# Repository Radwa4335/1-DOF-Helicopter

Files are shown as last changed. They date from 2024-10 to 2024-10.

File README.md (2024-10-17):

# 1-DOF-Helicopter with PD Controller
Project Overview
------------------
This project demonstrates the design and implementation of a 1-degree-of-freedom (1-DOF) helicopter model controlled using a Proportional-Derivative (PD) controller. The system focuses on controlling the pitch angle of the helicopter using real-time feedback from sensors and a control loop.

System Components
------------------
Arduino UNO: Used for signal processing and control implementation.
Coreless Motor: Drives the helicopter’s pitch movement.
MPU 6050 IMU Sensor: Provides real-time feedback on the helicopter's pitch angle.

Implementation
-----------------
The LabVIEW LINX Toolkit was used to interface with the Arduino UNO using serial communication.

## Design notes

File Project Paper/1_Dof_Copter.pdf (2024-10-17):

## Proportional-Derivative Control of a One Degree of Freedom Helicopter System: Dynamics and Implementation

Radwa Waheed 120200228 and Mohamed Khaled Mohamed 120210346 Under the Supervision of Prof. Ayman Nadaa

aEgypt Japan University of Science and Technology, , Borg El-Arab, , Alexandria, Egypt

Abstract

This study delves into the dynamics and control strategies of a One Degree of Freedom (One-DOF) helicopter system, serving as a simplified model for understanding rotary-wing aircraft behavior. The research focuses on addressing challenges related to stability and precision in helicopter flight, with a specific emphasis on the application of a Proportional-Derivative (PD) controller. The mechanical structure incorporates essential components such as a coreless motor, MPU 6050 IMU sensor, L298 motor driver, and an Arduino UNO microprocessor. Through the LabVIEW LINX Toolkit, a serial communication interface is established with the Arduino UNO to acquire gyroscope data from the MPU6050. Experimental results highlight the empirical determination of PD controller coefficients (Kp and Td) through systematic testing, showcasing the PD controller’s effectiveness in regulating the system’s motion.

Keywords: Rotary-Wing Aircraft Dynamics, PD Controller Tuning, One-DOF Helicopter Model, Arduino UNO Interface

### 1. Introduction

The one-degree-of-freedom helicopter, commonly known as the single-rotor helicopter, serves as a pivotal and streamlined model essential for comprehending the intricate dynamics and control principles inherent in rotary-wing aircraft. Within this system, the helicopter’s motion is intentionally confined to a singular rotational degree of freedom along its axis, strategically providing an optimal platform for the in-depth study of fundamental control strategies. This deliberate simplification distills the inherent complexities associated with full-scale helicopters, allowing researchers and engineers to focus with precision on critical aspects of control theory and dynamics. Within the realm of helicopter operations, a paramount challenge resides in the maintenance of stability and precision during flight. To address this challenge, sophisticated control algorithms are employed, with the Proportional-Derivative (PD) controller emerging as a preeminent choice. The PD controller stands as a universally embraced feedback control mechanism, skillfully adjusting the system’s behavior based on both the prevailing error and its rate of change. This strategic implementation empowers engineers to masterfully stabilize and regulate the helicopter’s motion, ensuring a responsive and meticulously controlled flight.

### 2. Materials

The essential components employed in this study are meticulously cataloged in Table 1, presenting a detailed inventory accompanied by visual representations, including Arduino UNO, Sensor Module, Coreless Motor, Propeller, L298N Motor Driver, and filament for the 3D printing of the structure.

Component | Image

Arduino UNO

IMU MPU6050

Coreless Motor

Propeller

L298N Motor Driver

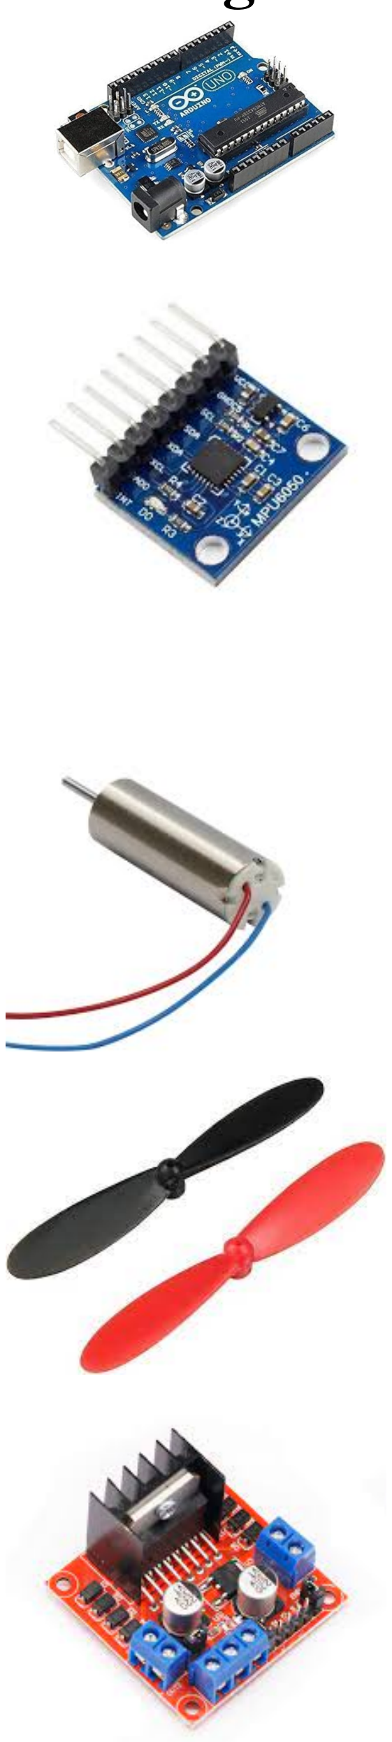
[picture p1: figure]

Table 1: Table of Components

Preprint submitted to Nuclear Physics A | January 20, 2024

### 3. Mathematical Model of the System

The equation of motion of the system is given by:

Jθ¨ = fthLm + mmgLmθ + msgLsθ

The Laplace-transformed equation is given by:

Fth(s) =

J
Lm

s

2Θ(s) + mmgsΘ(s) −

Ls
Lm

msgsΘ(s)

Fth(s) =

J
Lm

s

2 + mmgs −

Ls
Lm

msgs!
Θ(s)

G(s) =

1

J
Lm

s

2 + mmgs −

Ls
Lm

msgs

Given mm = 4.1674 grams, ms = 1.688 grams, Lm = 6.2 cm, Ls = 6.2 cm, mrod = 3.7146 grams, and Lrod = 16.1 cm, the open loop transfer function is given by:

G(s) =

1931.464
s

2 + 57.944

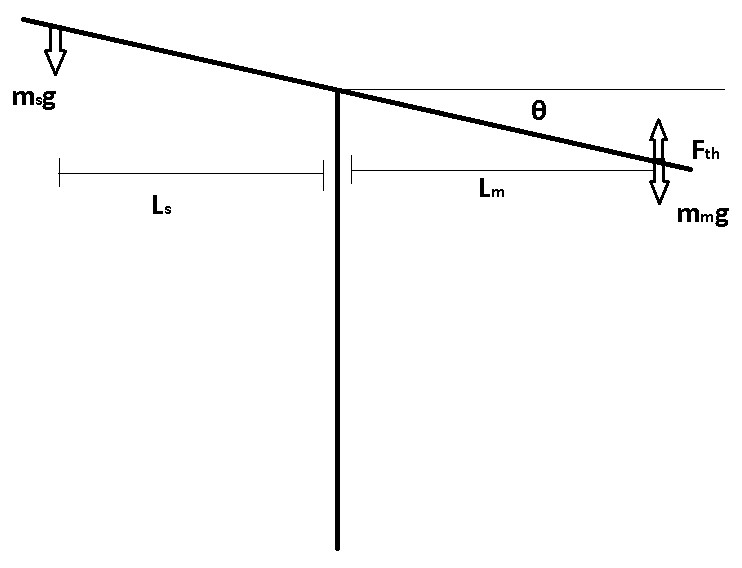
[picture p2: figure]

Figure 1: A Schematic of the System

The block diagram of the system us presendted in figure 3.

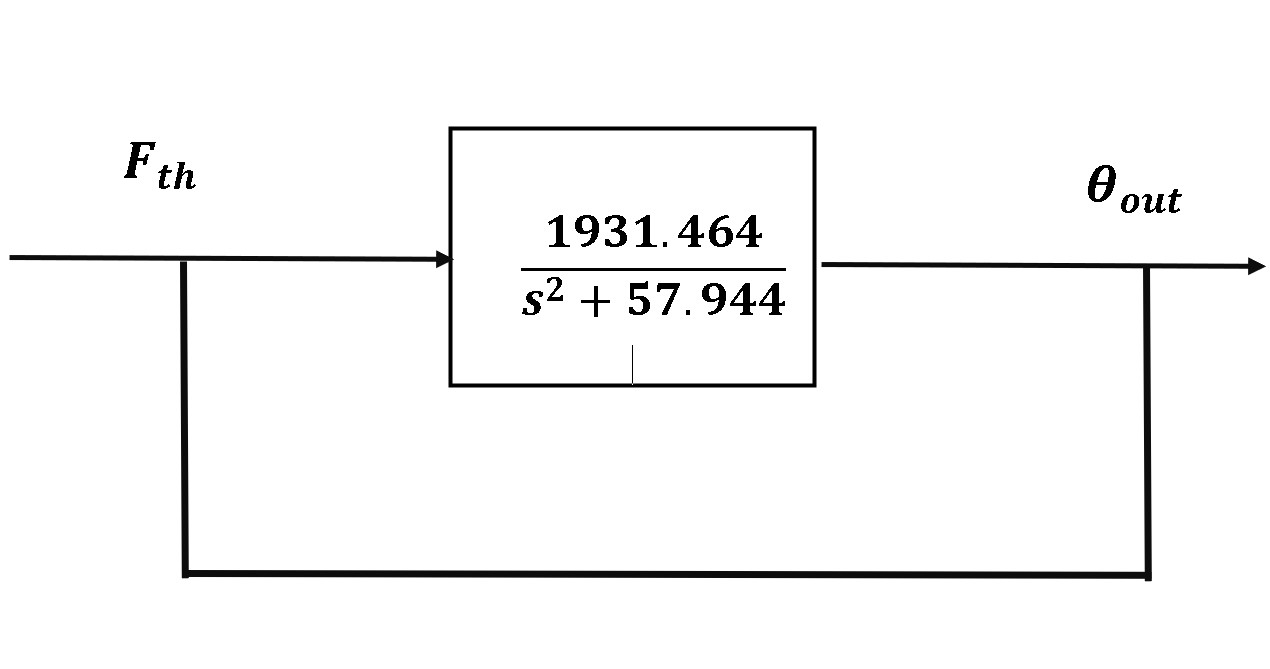
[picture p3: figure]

Figure 2: Block Diagram of the System

### 4. System Analysis and Controller Design

In the course of our investigation utilizing LabVIEW, we conducted a comprehensive analysis of the system, the results of which are presented in Figure 3 showcasing the system’s step response and Figure 4 illustrating the root locus. Notably, our findings indicate that the system exhibits instability, with dominant poles positioned along the imaginary axis. This significant observation provides valuable insights into the dynamic behavior of the system, specifically highlighting the presence of critical stability issues warranting further investigation and potential remedial measures.

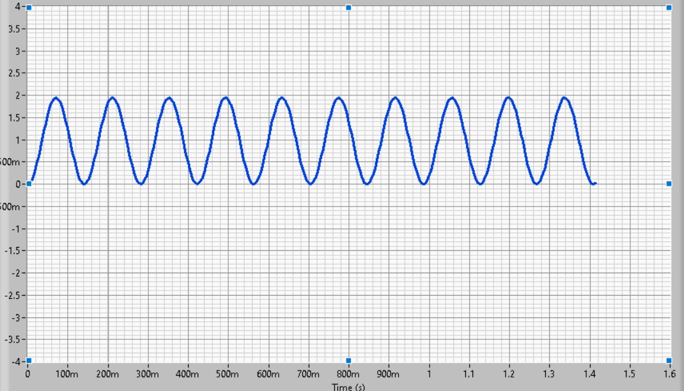
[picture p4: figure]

Figure 3: Step Response of the Uncompensated System

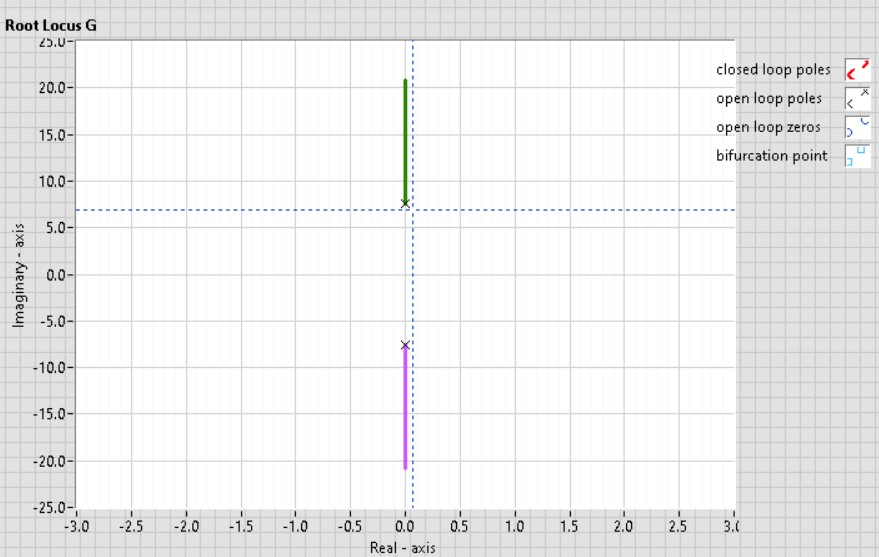
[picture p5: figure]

Figure 4: Root locus of the Uncompensated System

Commencing the design of the Proportional-Derivative (PD) controller involves the determination of critical parameters, specifically the critical gain (Kcr) and critical time (Pcr), essential for configuring the system’s stability and performance characteristics. And they were obtained as follows:
The characteristic equation is given by:

δ = s

2 + 1989.408

So, The critical gain is obtained from the gain of the system as: Kcrb = 1931.464.
By substituting s = jω into the characteristic equation, we obtain:

∆ = (jω)

2 + 1989.408

Simplifying further:

ω

2 = 1989.408

Hence, ω = 44.6

Therefore, the corresponding Critical periodic time (Pcr) is given by:

Pcr =

ω
2π

= 7.1 s

So, the values of the Proportional Gain (Kp) and Derivative Time (Td) obtained using LabVIEW are Kp = 4.5 and Td = 0.1, respectively.
The Root Locus and Step Response of the compensated system are illustrated in Figures 5 and 6, respectively. The analysis reveals a notable enhancement in system stability, achieving a settling time of less than 100 ms.

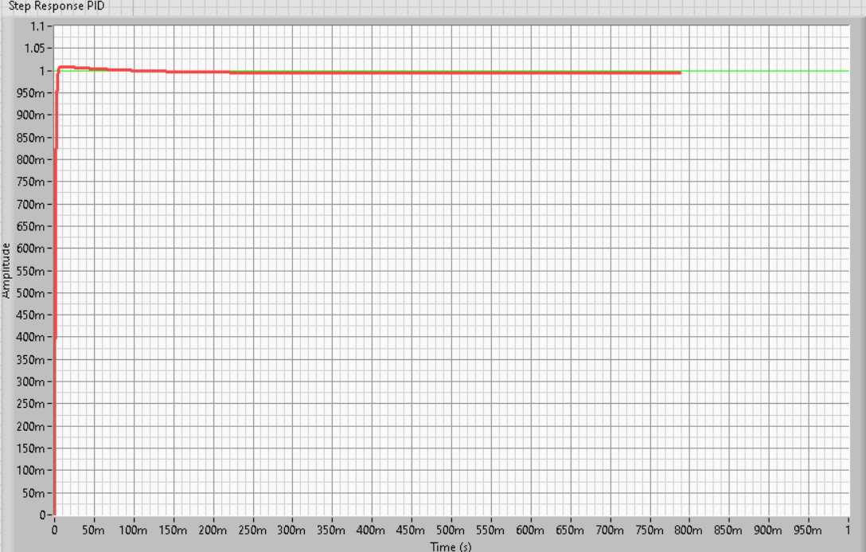
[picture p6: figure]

Figure 5: Step Response of the Compensated System

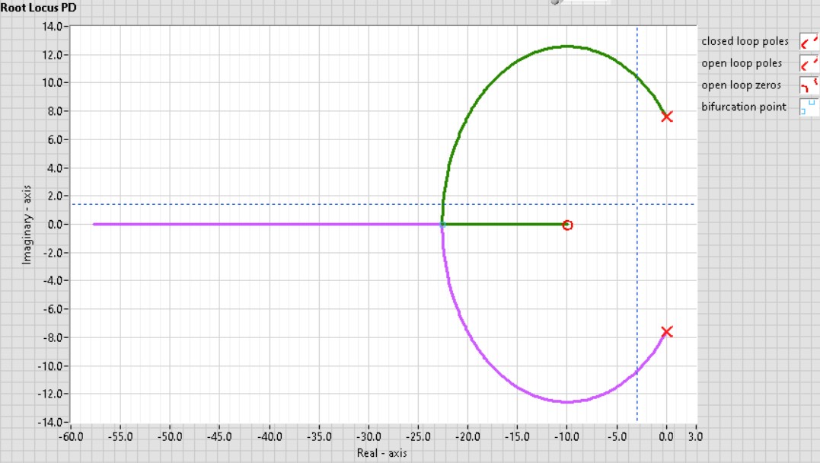
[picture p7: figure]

Figure 6: Root locus of the Compensated System

### 5. Real world Implementation

5.1. Hardware:
The project commenced with the acquisition of a 3D CAD model, meticulously tailored to meet our design specifications. After the design refinement, the model underwent fabrication through precision 3D printing technology. The mechanical configuration of the One-Degree-of-Freedom (One-DOF) helicopter system features a foundational base and two vertical plates, strategically separated by a support plate. Notably, a cylindrical structure, intricately connected to the main rod through precision bearings, constitutes a pivotal component of the system. Figure 7 encapsulates the comprehensive Solid Works drawing, providing an insightful visual representation of the intricacies inherent in the One-DOF helicopter’s mechanical structure.

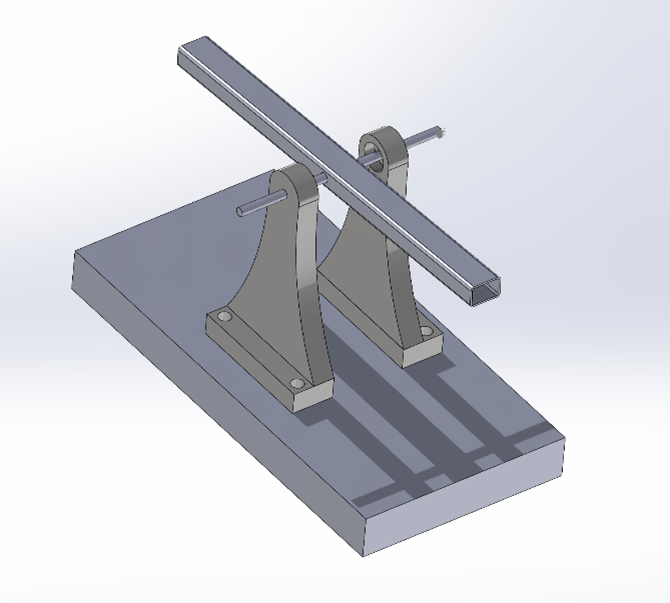
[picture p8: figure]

Figure 7: CAD Model of One-DOF Helicopter

The interconnection of the various components of the system, including the Coreless Motor, IMU sensor (MPU 6050), Motor Driver (L298), and Arduino UNO microprocessor, is illustrated in Figure 8.

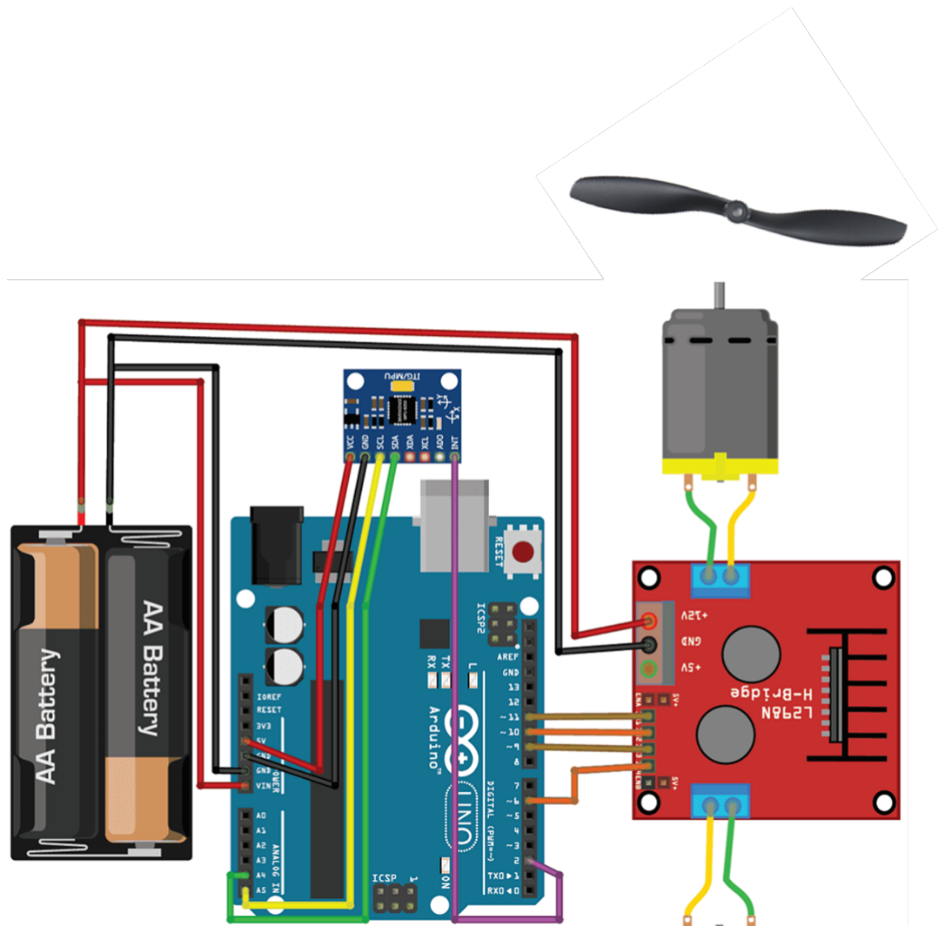
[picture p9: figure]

Figure 8: Interconnection of Components

5.2. Software:

The LabVIEW LINX Toolkit facilitated the interfacing with the Arduino UNO through serial communication. The interface was tailored to acquire gyroscope readings from the MPU6050. The implementation involves a while loop to continuously retrieve angle readings from the IMU, calculate motor power based on these readings, and apply the power to the plant. Figures (9) and (10) depict the front panel and block diagram of the LINX VI, respectively.

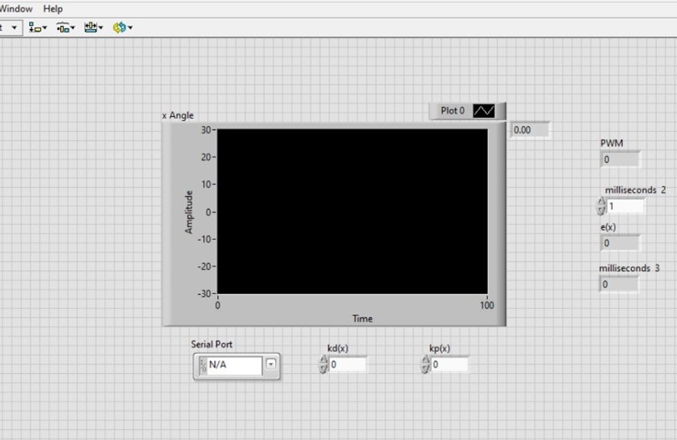
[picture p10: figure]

Figure 9: Front Panel illustrating real-time gyroscope readings

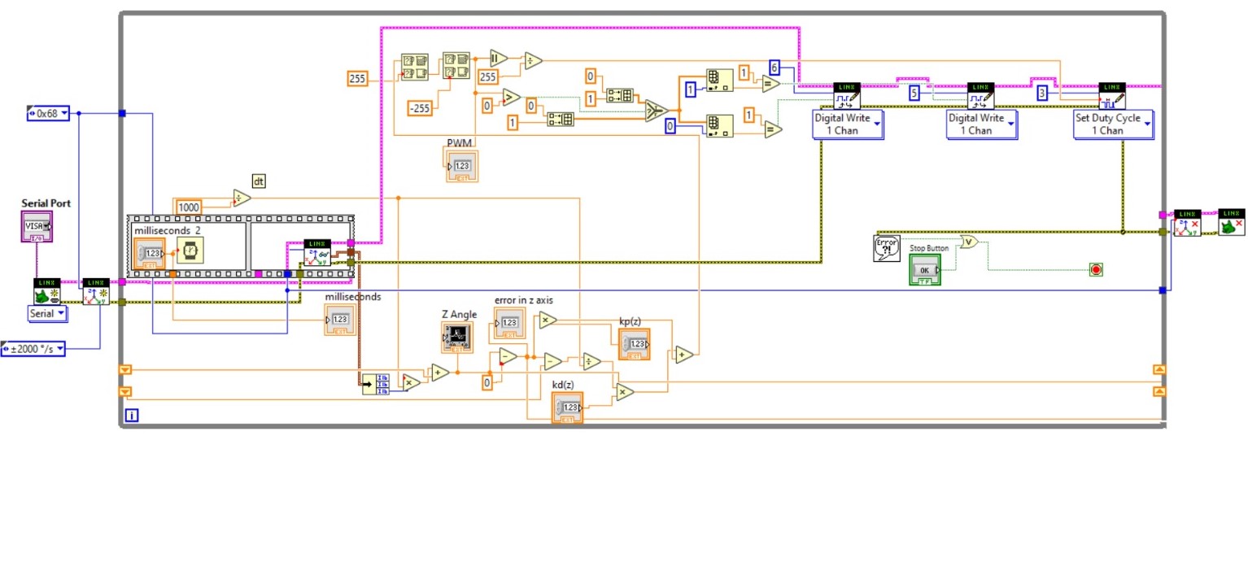
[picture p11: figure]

Figure 10: Block Diagram depicting the dynamic motor power application for plant control

5.3. Tuning of PD Controller Parameters:

The PD controller parameter coefficients, Kp and Td, were empirically determined in the experimentation process. Figure (11-a, b) showcases the system’s response under different Kp and Td values. Through analysis, it was observed that Kp = 4 and Td = 0.01 yielded the optimal response, demonstrating the effectiveness of these tuned parameters.

Future Recommendations

1. **State Feedback Theories Implementation:** Explore the application of advanced state feedback theories for control system design. Investigate techniques such as Linear Quadratic Regulator (LQR) or State Feedback with Observer for improved stability and performance.

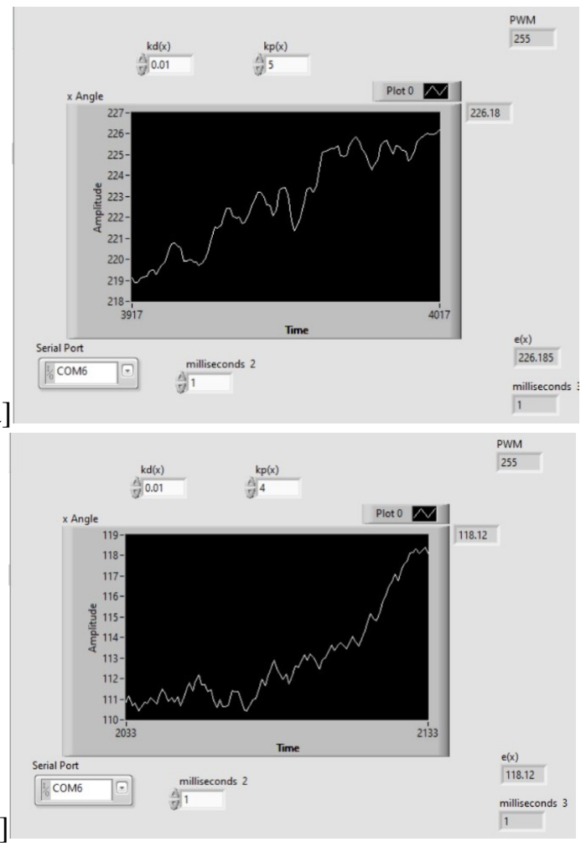
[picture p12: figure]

[Figure a]

[Figure b]

Figure 11: Various Instances from the Tuning Trials of PD Controller Parameters

2. **Sensor Reading Filtering with Kalman Filter:** Implement Kalman filtering techniques for sensor data fusion to enhance the accuracy and reliability of the system’s measurements. This can lead to improved control precision and robustness against noise and disturbances.
3. **Extension to Three Degrees of Freedom (3-DOF):** Consider expanding the project to a Three Degrees of Freedom (3-DOF) helicopter system. This extension would involve additional design considerations, such as incorporating lateral motion, and providing a more comprehensive platform for studying and implementing control strategies.

Conclusion

In conclusion, this project has laid the groundwork for the exploration and implementation of sophisticated control strategies and sensor technologies in the design of a One-Degreeof-Freedom helicopter system. The successful application of a Proportional-Derivative controller showcased the system’s stability and precision during vertical motion. Future endeavors could further advance the project by incorporating state feedback theories for enhanced control, implementing Kalman filters to refine sensor readings, and expanding the system to Three Degrees of Freedom (3-DOF) for a more comprehensive study. These recommendations open avenues for deeper research, innovation, and the potential application of the developed insights in diverse technological domains.

Acknowledgements

The completion of this research is attributed to Professor Ayman Nada’s exceptional mentorship and unwavering support. Special thanks to Teaching Assistant Hend Abdelaziz for valuable assistance, and to the university labs for essential resources. Their collective contributions were indispensable to the success of this endeavor.

References

[1] Mane, R., Mahapatro, K. A. Gundecha, A. D., (2019). “Single Degree of Freedom Helicopter Model: Laboratory Setup Design”. 2019 International Conference on Advances in Computing, Communication and Control (ICAC3), IEEE, Mumbai, India. [2] Jafar, A., Ahmad, S. M. Ahmed N.

(2016). ”Mathematical modeling and control law design for 1DOF Quadcopter flight dynamics,” 2016 International Conference on Computing, Electronic and Electrical Engineering (ICE Cube), pp. 79-84, IEEE, Quetta, Pakistan.

[3] QNET Vertical take-off and landing trainer for NI-ELVIS, Quanser Inc., 2009.

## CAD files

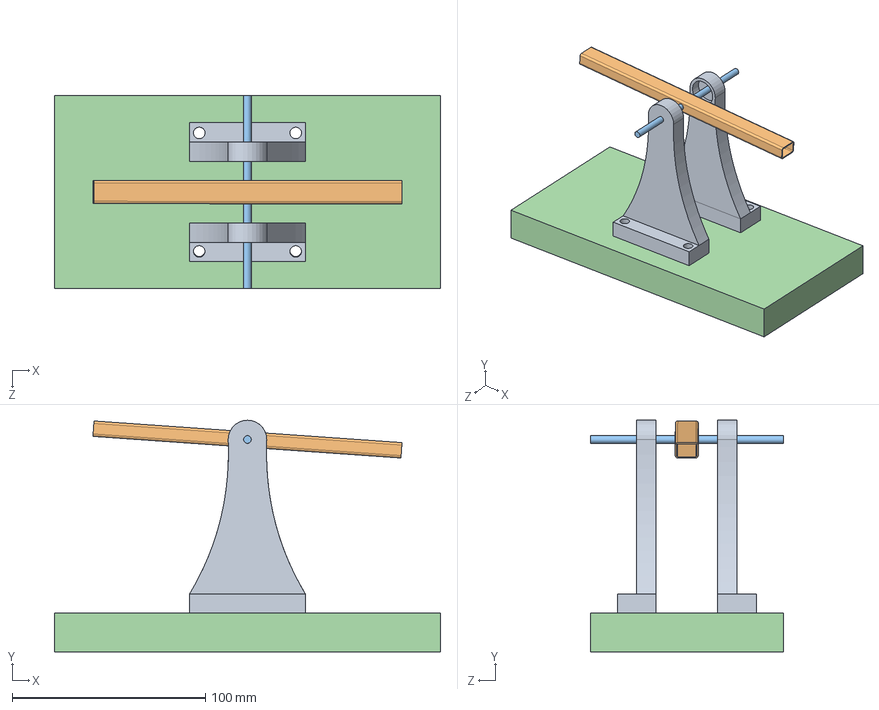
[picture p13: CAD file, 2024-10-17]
SOLIDWORKS Design/Montaj3.SLDASM
200.0 x 120.0 x 100.2 mm
Parça3 x 2
profil
saplama
base

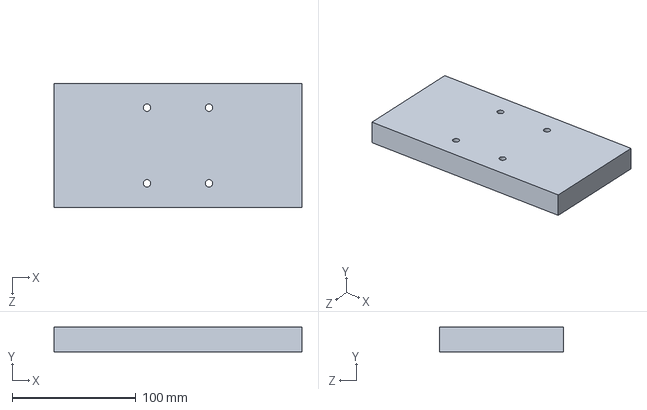
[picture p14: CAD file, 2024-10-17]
SOLIDWORKS Design/base.SLDPRT
200.0 x 20.0 x 100.0 mm

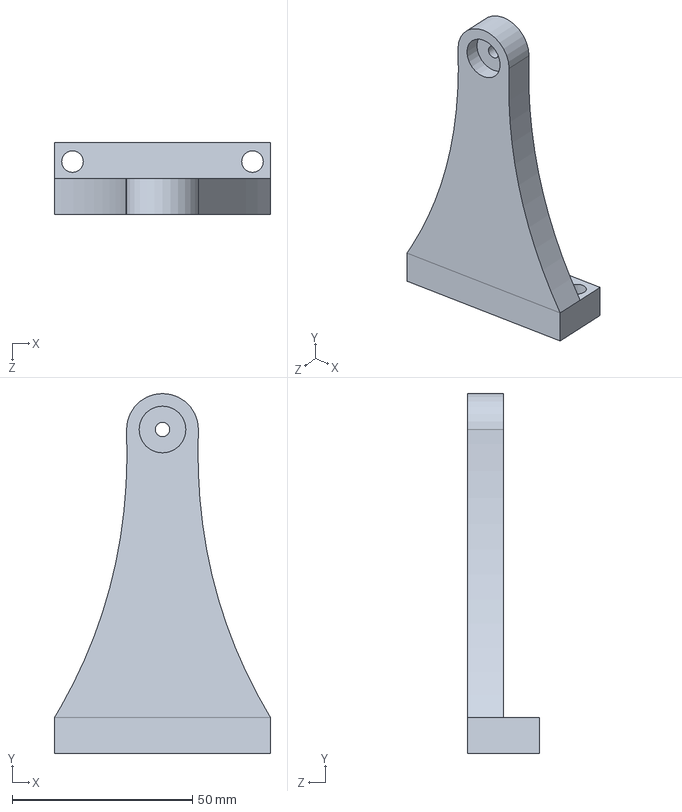
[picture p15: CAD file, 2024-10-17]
SOLIDWORKS Design/Parça3.SLDPRT
60.0 x 100.0 x 20.0 mm

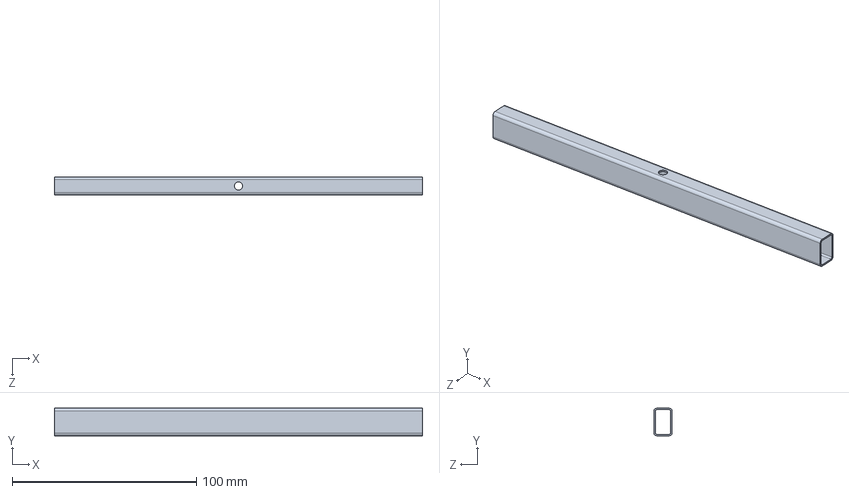
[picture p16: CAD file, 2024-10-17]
SOLIDWORKS Design/profil.SLDPRT
200.0 x 15.0 x 10.0 mm

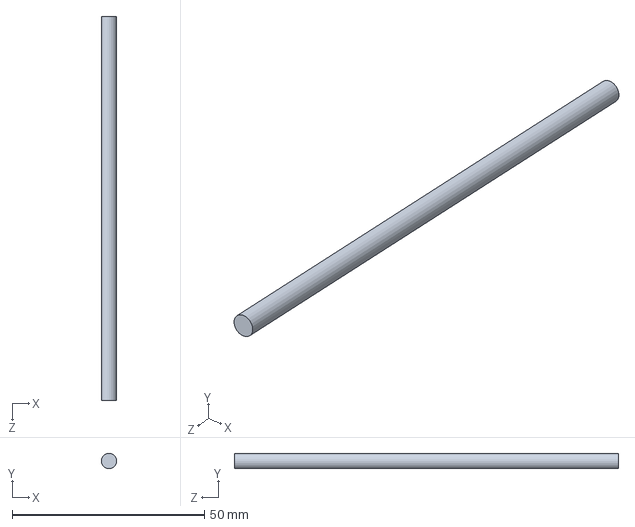
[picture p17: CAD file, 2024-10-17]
SOLIDWORKS Design/saplama.SLDPRT
4.00 x 4.00 x 100.0 mm

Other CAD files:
SOLIDWORKS Design/Parça3.STL
SOLIDWORKS Design/base.STL
SOLIDWORKS Design/profil.STL
SOLIDWORKS Design/saplama.STL
